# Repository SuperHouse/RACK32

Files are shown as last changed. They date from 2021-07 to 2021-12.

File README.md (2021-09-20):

Rack32 ESP32 rack-mount controller with Ethernet
================================================

Copyright 2021 SuperHouse Automation Pty Ltd  www.superhouse.tv

A general purpose control board for rack mount projects, compatible
with the [Open eXtensible Rack System](https://oxrs.io/).

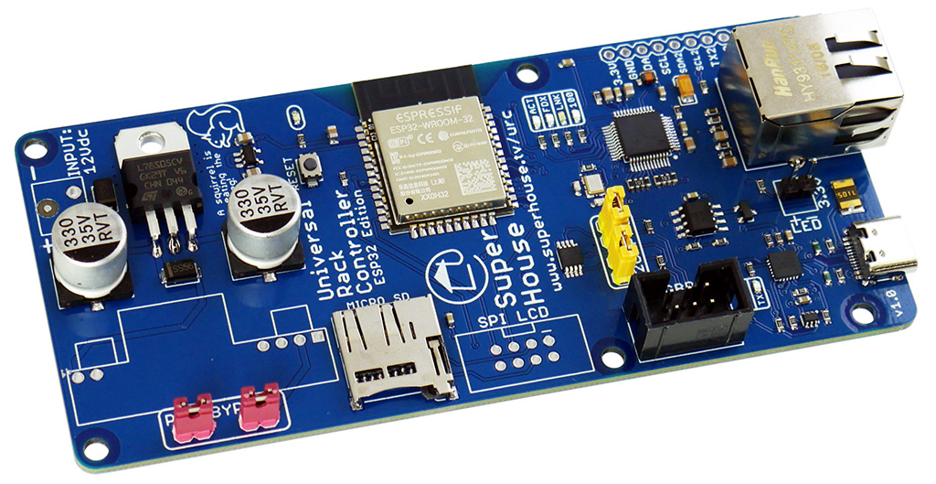
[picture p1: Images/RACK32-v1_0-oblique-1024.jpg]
Rack32 PCB


DIY rack-mount projects often require an Ethernet connection, a
status display, power regulation, and other features that are not
specific to the project.

This board fits into a rack-mount case and provides those common
features so they don't have to be recreated every time.

Features:

 * ESP32 microcontroller with WiFi.
 * 10/100Mbps Ethernet.
 * Support for both DIY (12V) PoE and 48V 802.3af PoE.
 * Pluggable terminal block for optional external DC power input.
 * Automotive-grade voltage regulator for harsh electrical environments.
 * 6-way IDC "I2C-Breakout" header for linking to other boards.
 * 8-way IDC "SPI-LCD" header for connection to an LCD.
 * USB-C connector for loading firmware.
 * Auto power source selection between USB-C, PoE, and external DC.
 * I/O header with power, 2 x I2C ports, and second hardware serial port.
 * Micro SD card slot for config files, logs, and media storage.
 * Onboard temperature sensor.
 * Header for front-panel power LED.
 * Can be built with onboard PCB antenna or external WiFi antenna.

More information:

  [www.superhouse.tv/rack32](http://www.superhouse.tv/rack32)

INSTALLATION
------------
The design is saved as an EAGLE project. EAGLE PCB design software is
available from www.cadsoftusa.com free for non-commercial use. To use
this project download it and place the directory containing these files
into the "eagle" directory on your computer. Then open EAGLE and
navigate to the project.

CREDITS
-------
Designed by Jonathan Oxer jon@oxer.com.au

DISTRIBUTION
------------
The specific terms of distribution of this project are governed by the
license referenced below.

LICENSE
-------
Licensed under the TAPR Open Hardware License (www.tapr.org/OHL).
The "license" folder within this repository also contains a copy of
this license in plain text format.

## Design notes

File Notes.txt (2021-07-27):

TFT control with CS tied to GND:

https://github.com/Bodmer/TFT_eSPI/issues/163

https://www.instructables.com/Adding-CS-Pin-to-13-LCD/

These Adafruit modules solve the CS pin problem and have an onboard micro SD
card slot, but they're very expensive. We could make different carrier
boards for this or the dodgy AliExpress ones that don't have CS. Maybe a
tri-state buffer on the carrier board to avoid having to rework the cheap
displays?

https://learn.adafruit.com/adafruit-1-3-and-1-54-240-x-240-wide-angle-tft-lcd-displays?view=all

Pins required:
Pin  ESP32          LCD
1    GND            GND
2    3.3V           VCC (should be compatible with either 3.3V or 5V)
3    IO18_SCLK      TFT_SCLK
4    IO23_COPI      TFT_COPI
5    IO4_TFT_RST    TFT_RST
6    IO2_TFT_DC     TFT_DC
7    IO ?           TFT_BLK (backlight control)
8    IO ?           TFT_CS (doesn't exist on cheap module: control buffer?)

  IO22   TFT_CIPO (not used on cheap module: required for Adafruit with micro SD card)

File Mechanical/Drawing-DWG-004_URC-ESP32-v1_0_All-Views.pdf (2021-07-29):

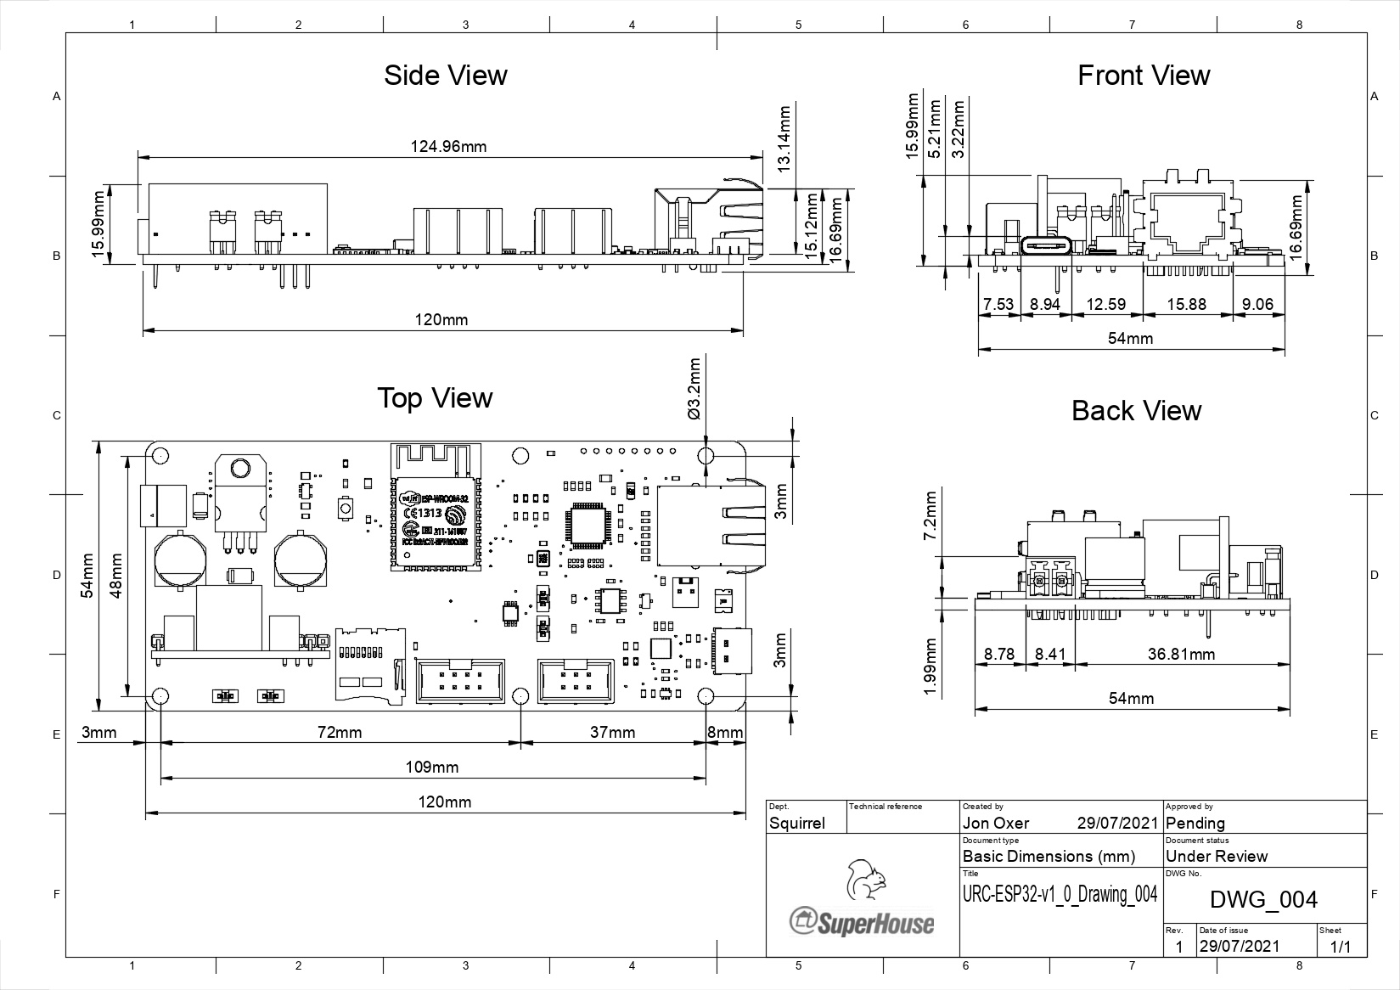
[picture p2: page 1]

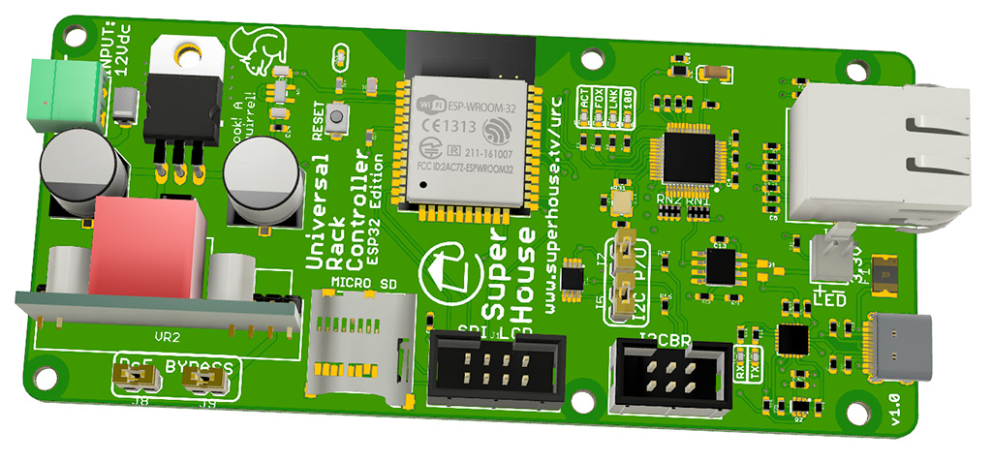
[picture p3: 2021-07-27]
Images/URC-ESP32-v1_0-render.jpg

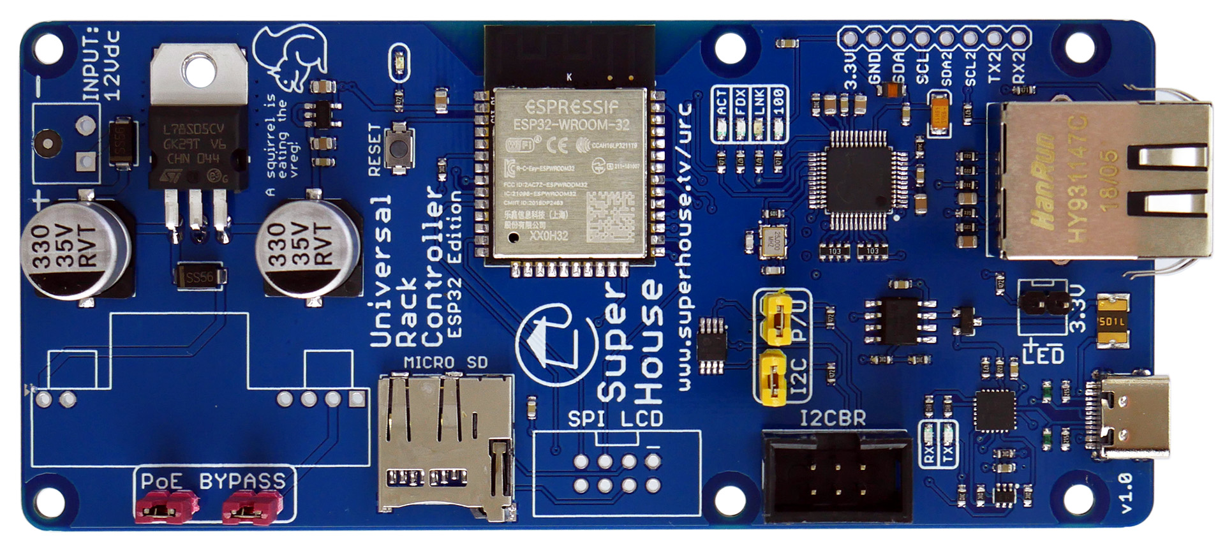
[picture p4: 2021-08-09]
Images/RACK32-v1_0-top.jpg

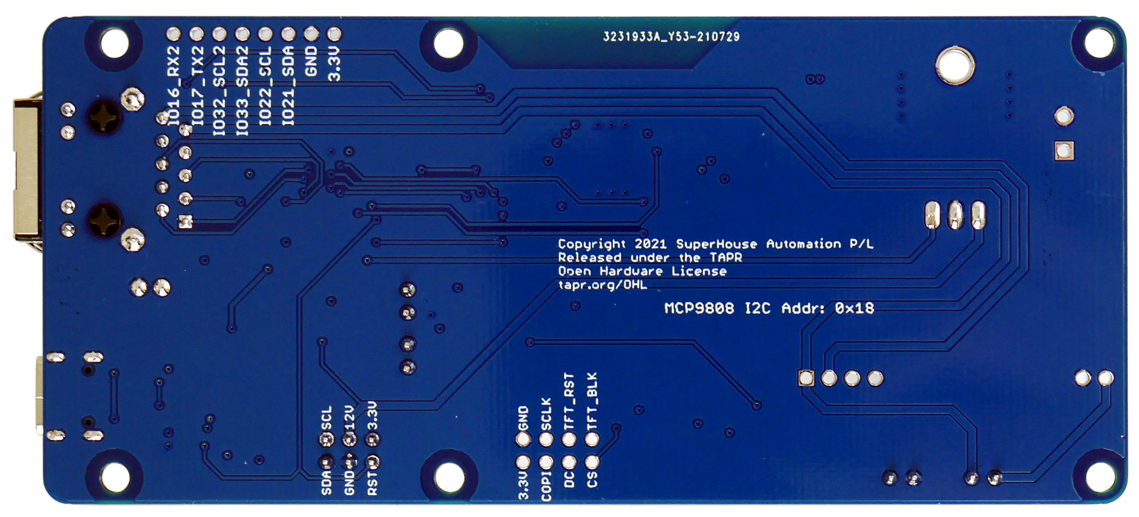
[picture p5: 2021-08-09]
Images/RACK32-v1_0-bottom.jpg

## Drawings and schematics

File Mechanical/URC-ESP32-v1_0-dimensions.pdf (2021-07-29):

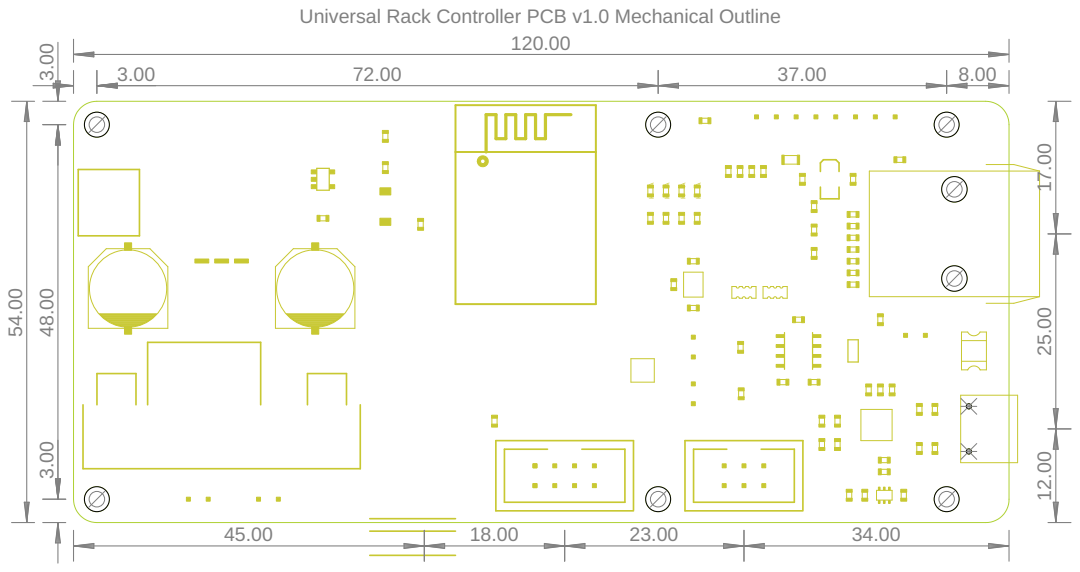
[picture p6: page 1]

Universal Rack Controller PCB v1.0 Mechanical Outline

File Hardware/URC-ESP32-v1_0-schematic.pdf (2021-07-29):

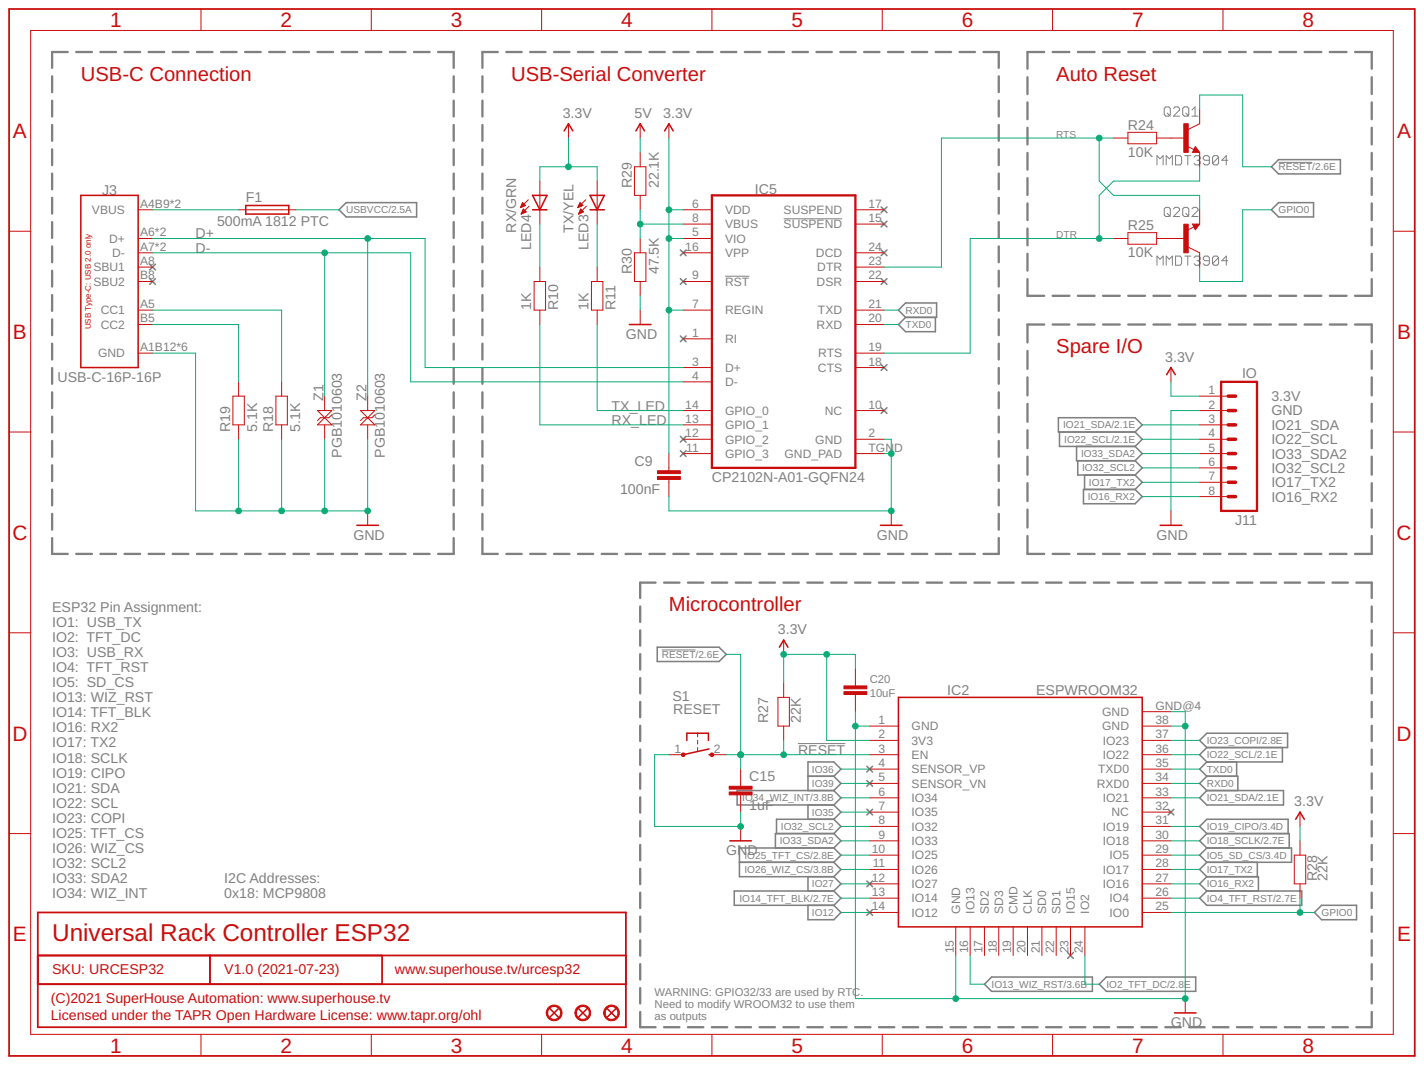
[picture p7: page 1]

8 | | 15 SUSPEND
5 | | 24

USB Type-C: USB 2.0 only

TX_LED | 14

2 | 37 GND
3 | 36

SKU: URCESP32
(C)2021 SuperHouse Automation: www.superhouse.tv Licensed under the TAPR Open Hardware License: www.tapr.org/ohl

WARNING: GPIO32/33 are used by RTC. Need to modify WROOM32 to use them
as outputs

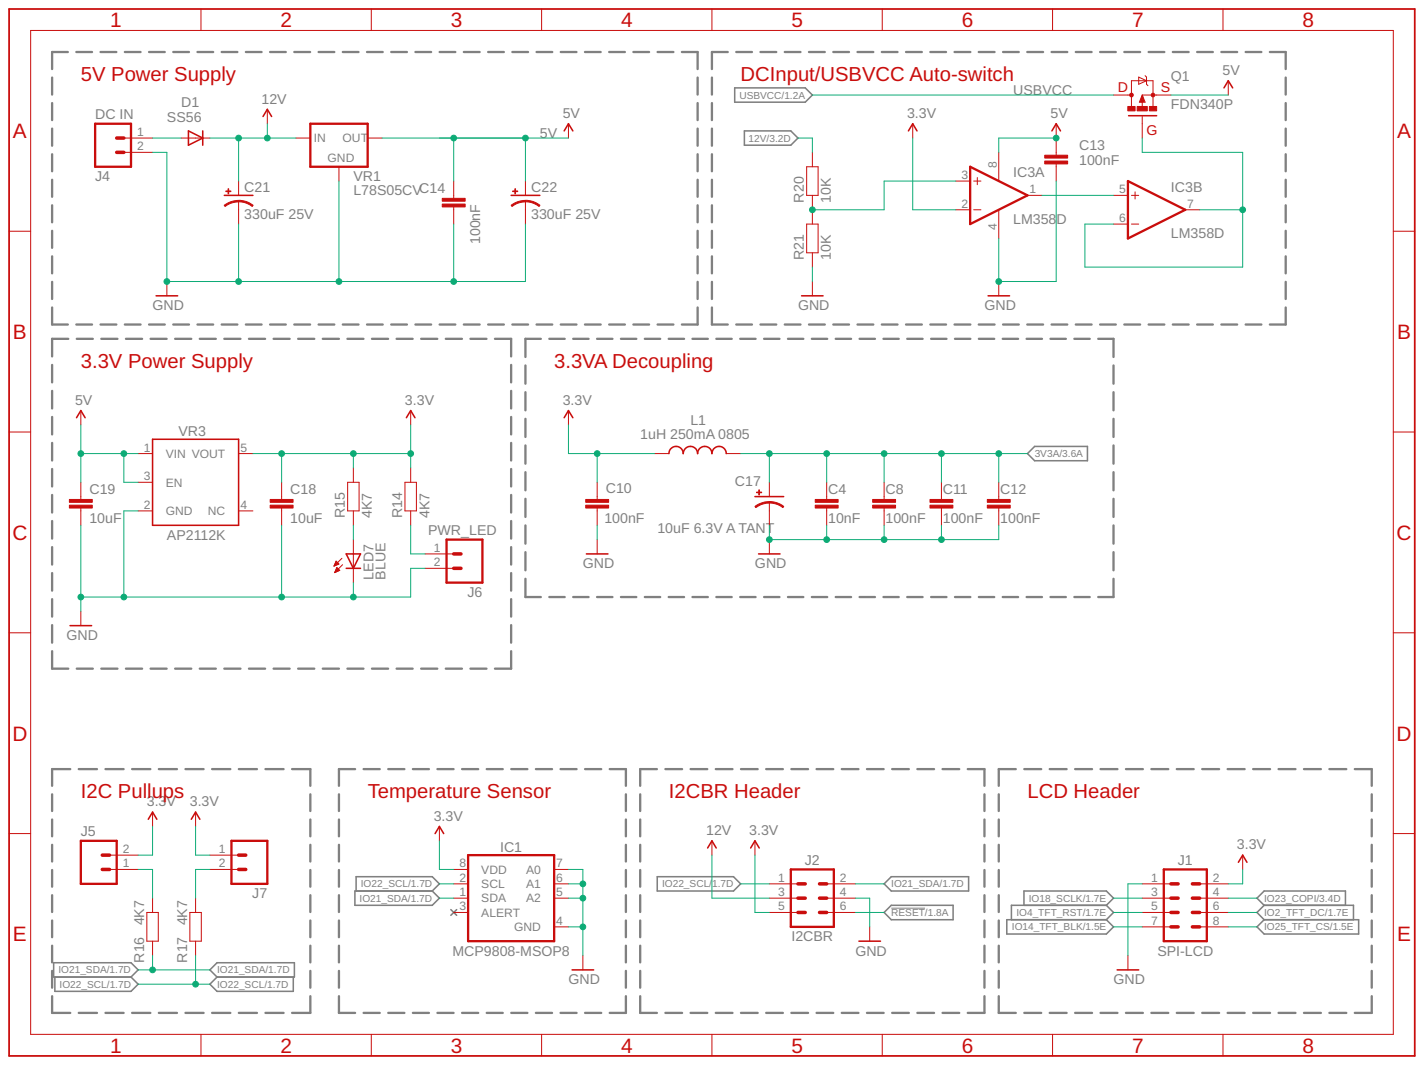
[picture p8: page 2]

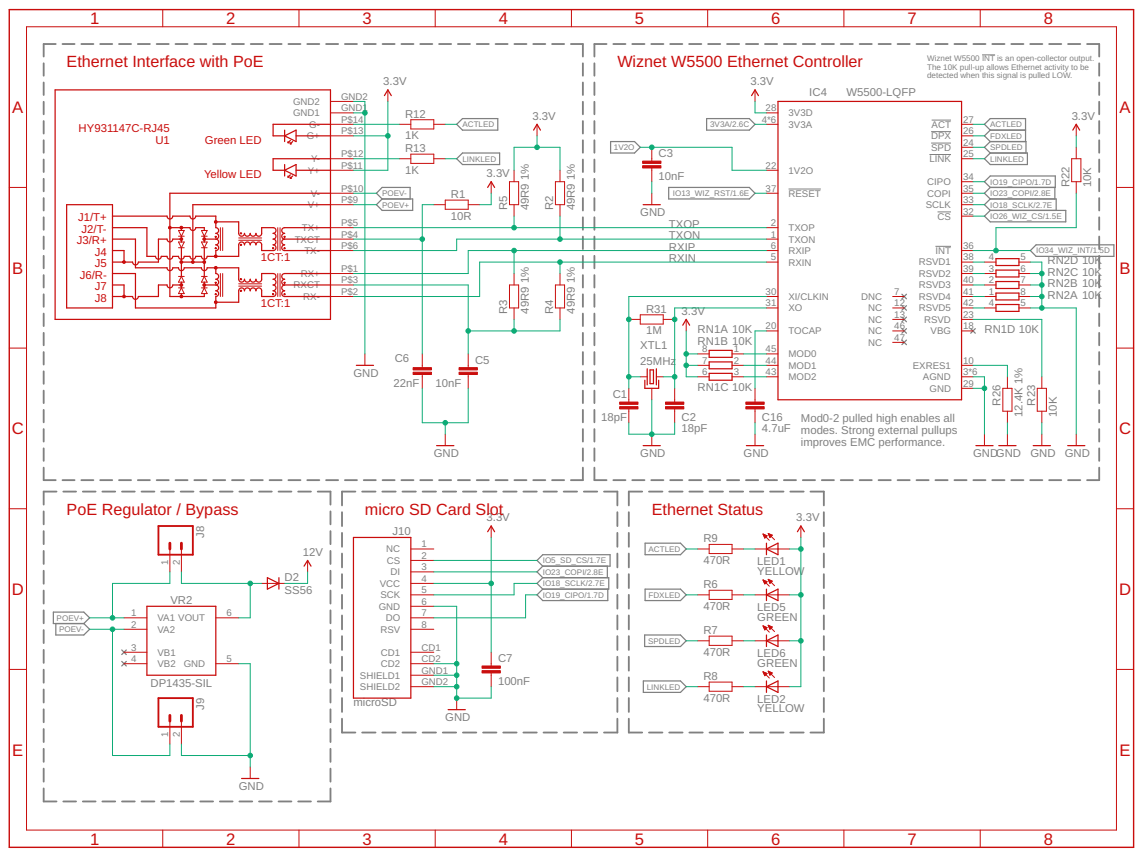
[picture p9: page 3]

Wiznet W5500 INT is an open-collector output. The 10K pull-up allows Ethernet activity to be

detected when this signal is pulled LOW.

7 2
6 3 | 3*6

Mod0-2 pulled high enables all modes. Strong external pullups

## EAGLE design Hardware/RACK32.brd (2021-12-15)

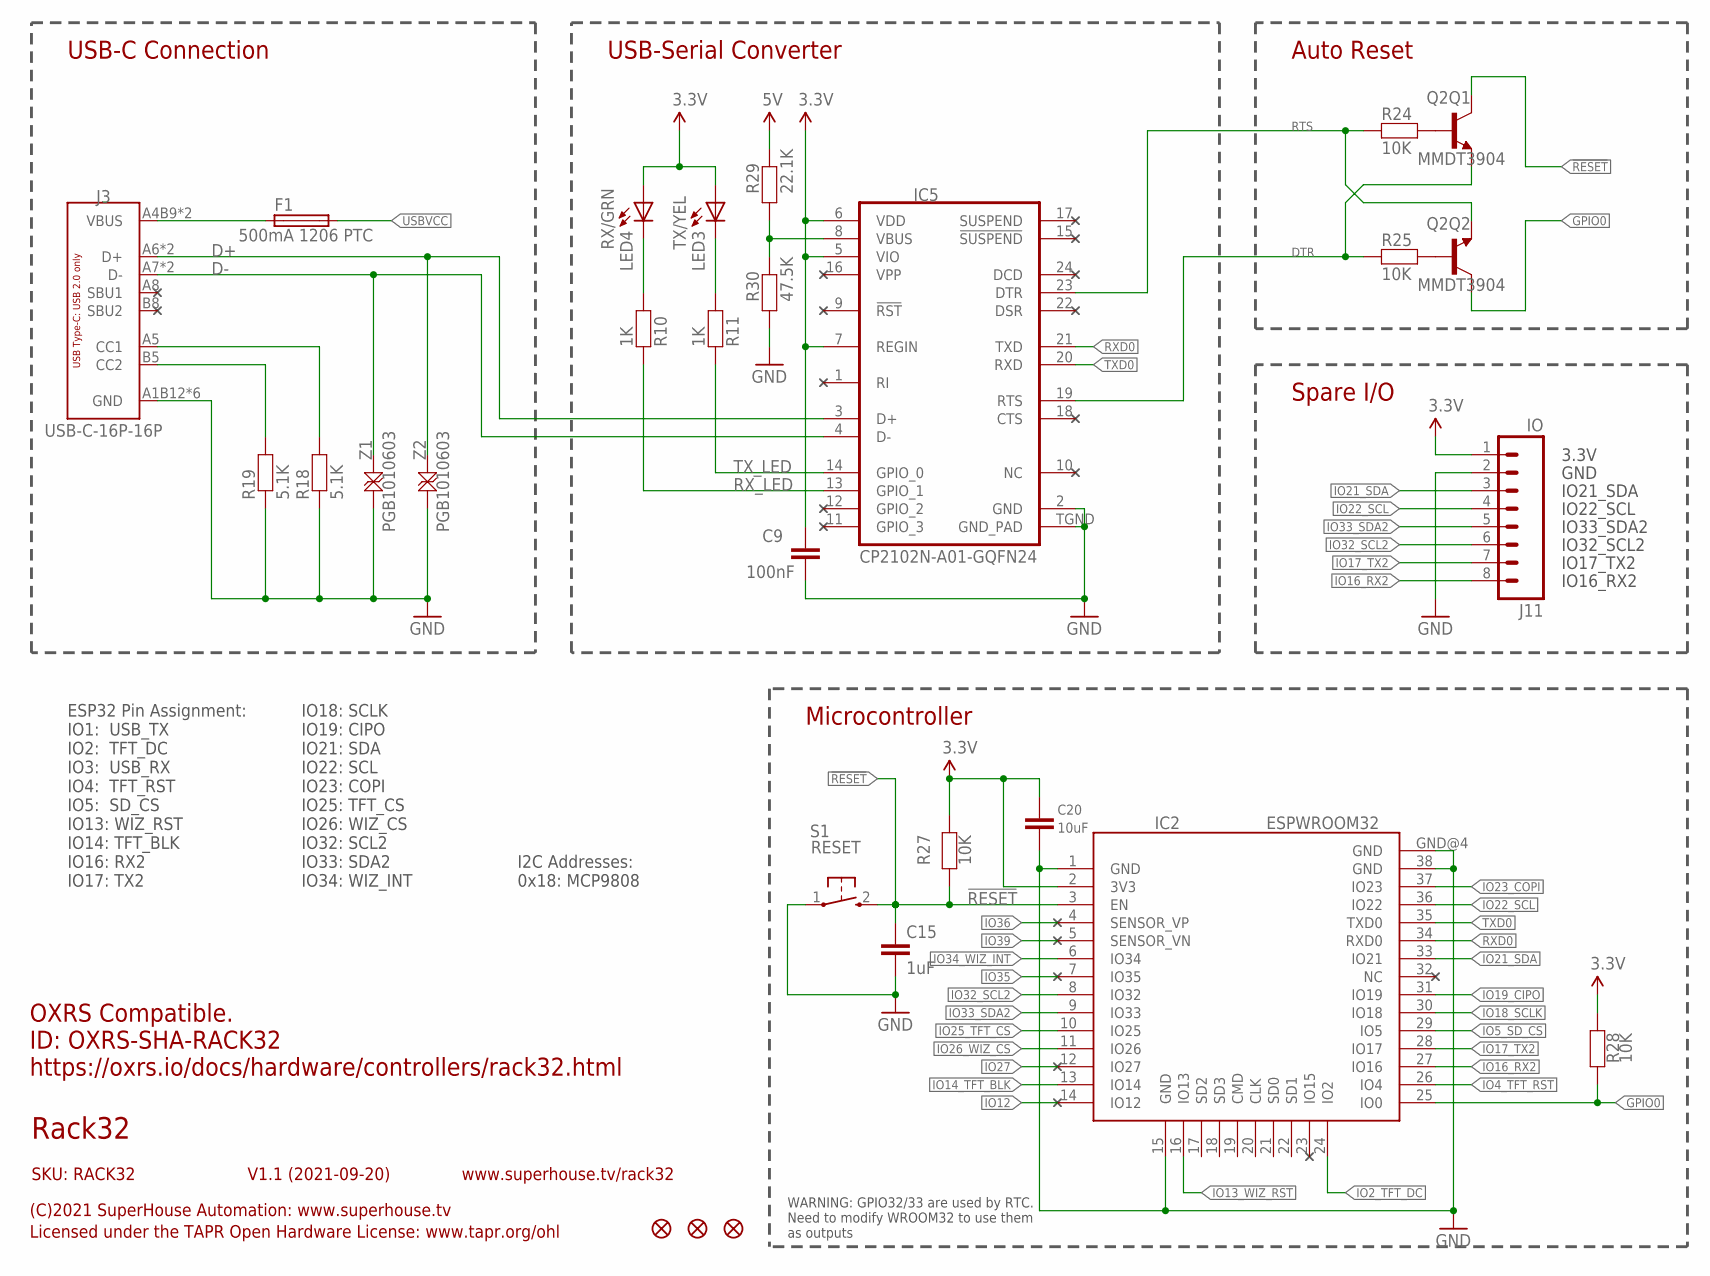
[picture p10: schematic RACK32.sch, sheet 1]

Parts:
C9: 100nF; C0603
C15: 1uF; C0603
C20: 10uF; C0805
F1: 500mA 1206 PTC; 1206
FID1, FID2, FID3: FIDUCIAL1X2.5; FIDUCIAL-1X2.5
IC2: ESPWROOM32
IC5: CP2102N-A01-GQFN24; QFN-24
J3: USB-C-16P-16P; USB-C-16P
J11: IO; 1X08
LED3: TX/YEL; LED-0603
LED4: RX/GRN; LED-0603
Q2: MMDT3904; SOT-363
R10, R11: 1K; R0603
R18, R19: 5.1K; R0603
R24, R25, R27, R28: 10K; R0603
R29: 22.1K; R0603
R30: 47.5K; R0603
S1: RESET; TACTILE_SMT_3X4X2
Z1, Z2: PGB1010603; TVS0603

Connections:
3.3V: C9.1, C20.1, IC2.2 (3V3), IC5.5 (VIO), IC5.6 (VDD), IC5.7 (REGIN), J11.1, LED3.A, LED4.A, R27.1, R28.1; also elsewhere on the board
5V: R29.2; also elsewhere on the board
!RESET: C15.1, IC2.3 (EN), Q2.3 (C), R27.2, S1.2 (S); also elsewhere on the board
D+: IC5.3 (D+), J3.A6 (D+), J3.B6 (D+), Z2.2
D-: IC5.4 (D-), J3.A7 (D-), J3.B7 (D-), Z1.2
DTR: IC5.23 (DTR), Q2.1 (E), R24.1
GND: C9.2, C15.2, C20.2, IC2.1 (GND), IC2.15 (GND), IC2.38 (GND), IC2.GND@4 (GND), IC5.2 (GND), IC5.TGND (GND_PAD), J3.A1B12 (GND), J3.A12B1 (GND), J3.FIX1 (GND), J3.FIX2 (GND), J3.FIX3 (GND), J3.FIX4 (GND), J11.2, R18.1, R19.1, R30.1, S1.1, Z1.1, Z2.1; also elsewhere on the board
GPIO0: IC2.25 (IO0), Q2.6 (C), R28.2
IO2_TFT_DC: IC2.24 (IO2); also elsewhere on the board
IO4_TFT_RST: IC2.26 (IO4); also elsewhere on the board
IO5_SD_CS: IC2.29 (IO5); also elsewhere on the board
IO12: IC2.14 (IO12)
IO13_WIZ_RST: IC2.16 (IO13); also elsewhere on the board
IO14_TFT_BLK: IC2.13 (IO14); also elsewhere on the board
IO16_RX2: IC2.27 (IO16), J11.8
IO17_TX2: IC2.28 (IO17), J11.7
IO18_SCLK: IC2.30 (IO18); also elsewhere on the board
IO19_CIPO: IC2.31 (IO19); also elsewhere on the board
IO21_SDA: IC2.33 (IO21), J11.3; also elsewhere on the board
IO22_SCL: IC2.36 (IO22), J11.4; also elsewhere on the board
IO23_COPI: IC2.37 (IO23); also elsewhere on the board
IO25_TFT_CS: IC2.10 (IO25); also elsewhere on the board
IO26_WIZ_CS: IC2.11 (IO26); also elsewhere on the board
IO27: IC2.12 (IO27)
IO32_SCL2: IC2.8 (IO32), J11.6
IO33_SDA2: IC2.9 (IO33), J11.5
IO34_WIZ_INT: IC2.6 (IO34); also elsewhere on the board
IO35: IC2.7 (IO35)
IO36: IC2.4 (SENSOR_VP)
IO39: IC2.5 (SENSOR_VN)
unnamed: Q2.2 (B), R25.2
unnamed: J3.B5 (CC2), R19.2
unnamed: J3.A5 (CC1), R18.2
unnamed: Q2.5 (B), R24.2
unnamed: LED3.C, R11.2
unnamed: LED4.C, R10.2
unnamed: IC5.8 (VBUS), R29.1, R30.2
RTS: IC5.19 (RTS), Q2.4 (E), R25.1
RXD0: IC2.34 (RXD0), IC5.21 (TXD)
RX_LED: IC5.13 (GPIO_1), R10.1
TXD0: IC2.35 (TXD0), IC5.20 (RXD)
TX_LED: IC5.14 (GPIO_0), R11.1
USBVCC: F1.2; also elsewhere on the board
USBVIN: F1.1, J3.A4B9 (VBUS), J3.A9B4 (VBUS)

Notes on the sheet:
USB-C Connection
USB-Serial Converter
Auto Reset
Microcontroller
WARNING: GPIO32/33 are used by RTC. Need to modify WROOM32 to use them as outputs
I2C Addresses: 0x18: MCP9808
ESP32 Pin Assignment: IO1: USB_TX IO2: TFT_DC IO3: USB_RX IO4: TFT_RST IO5: SD_CS IO13: WIZ_RST IO14: TFT_BLK IO16: RX2 IO17: TX2
Rack32
SKU: RACK32
(C)2021 SuperHouse Automation: www.superhouse.tv
Licensed under the TAPR Open Hardware License: www.tapr.org/ohl
www.superhouse.tv/rack32
V1.1 (2021-09-20)
Spare I/O
3.3V
GND
IO21_SDA
IO22_SCL
IO33_SDA2
IO32_SCL2
IO17_TX2
IO16_RX2
OXRS Compatible. ID: OXRS-SHA-RACK32 https://oxrs.io/docs/hardware/controllers/rack32.html
IO18: SCLK IO19: CIPO IO21: SDA IO22: SCL IO23: COPI IO25: TFT_CS IO26: WIZ_CS IO32: SCL2 IO33: SDA2 IO34: WIZ_INT

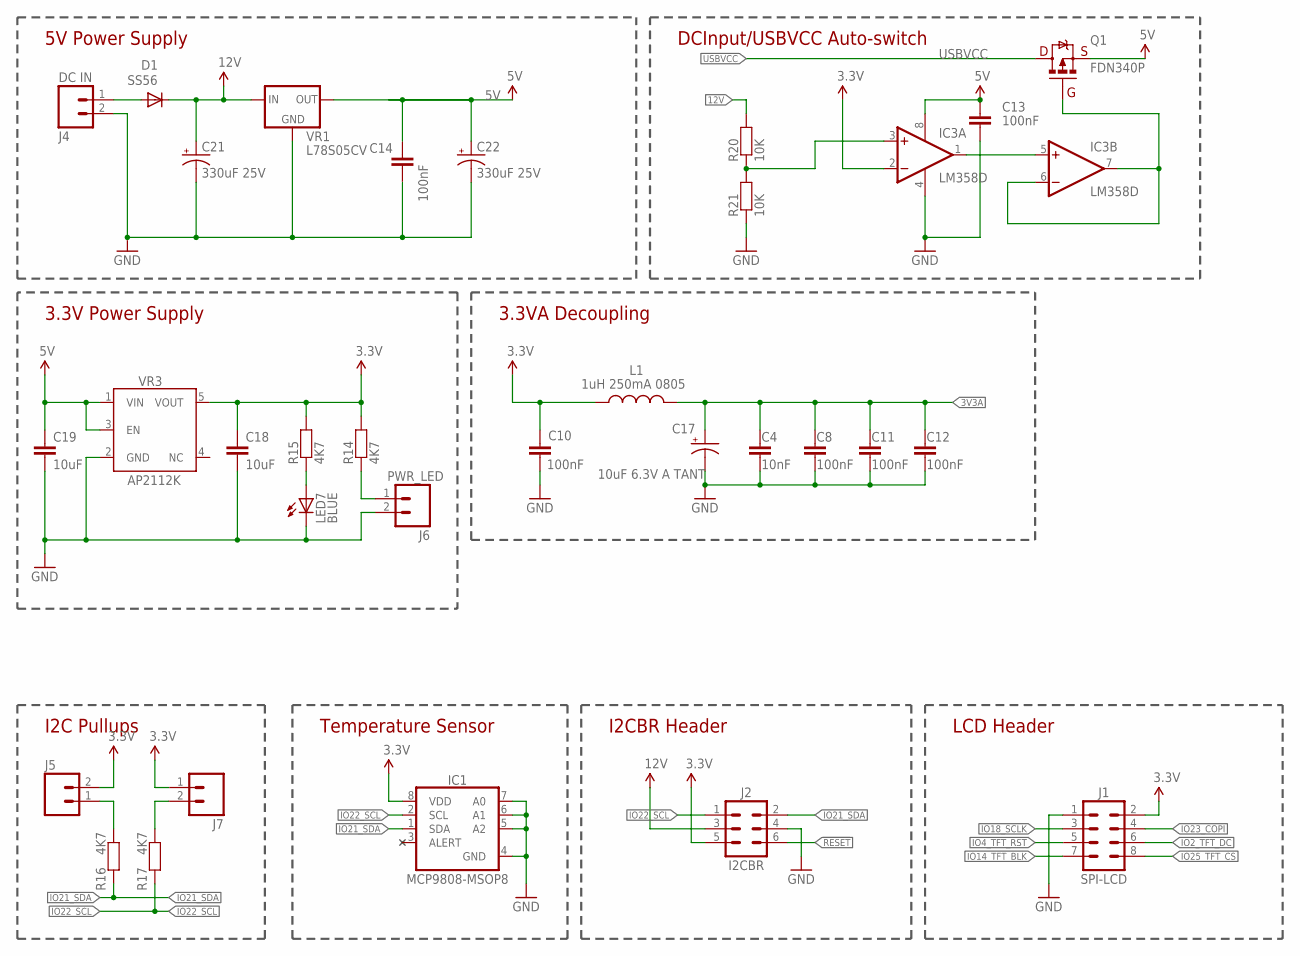
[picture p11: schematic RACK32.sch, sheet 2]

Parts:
C4: 10nF; C0603
C8, C10, C11, C12, C13, C14: 100nF; C0603
C17: 10uF 6.3V A TANT; EIA3216
C18, C19: 10uF; C0805
C21, C22: 330uF 25V; PANASONIC_G
D1: SS56; SMA-DIODE
IC1: MCP9808-MSOP8; MSOP-8
IC3: LM358D; SO08
J1: SPI-LCD; 2X04-2.54-SHROUDED
J2: I2CBR; 2X3-2.54-SHROUDED
J4: DC IN; SCREWTERMINAL-3.81MM-HOR-2
J5, J7: M02-PIN-JUMP-Y; 1X02-P-JUMP-Y
J6: PWR_LED; 1X02-P
L1: 1uH 250mA 0805; L2012C
LED7: BLUE; LED-0603
Q1: FDN340P; SOT23-3
R14, R15, R16, R17: 4K7; R0603
R20, R21: 10K; R0603
VR1: L78S05CV; TO220
VR3: AP2112KSOT25; SOT23-5

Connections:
3.3V: C10.1, C18.1, IC1.8 (VDD), IC3.2 (-IN), J1.2, J2.5, J5.2, J7.1, L1.1, R14.2, R15.2, VR3.5 (VOUT); also elsewhere on the board
3V3A: C4.1, C8.1, C11.1, C12.1, C17.A (+), L1.2; also elsewhere on the board
5V: C13.1, C14.1, C19.1, C22.+, IC3.8 (V+), Q1.2 (S), VR1.3 (OUT), VR3.1 (VIN), VR3.3 (EN); also elsewhere on the board
12V: C21.+, D1.C, J2.3, R20.2, VR1.1 (IN); also elsewhere on the board
!RESET: J2.6; also elsewhere on the board
GND: C4.2, C8.2, C10.2, C11.2, C12.2, C13.2, C14.2, C17.C (-), C18.2, C19.2, C21.-, C22.-, IC1.4 (GND), IC1.5 (A2), IC1.6 (A1), IC1.7 (A0), IC3.4 (V-), J1.1, J2.4, J4.2, J6.2, LED7.C, R21.1, VR1.2 (GND), VR1.HEATSINK (GND), VR1.TAB (GND), VR3.2 (GND); also elsewhere on the board
IO2_TFT_DC: J1.6; also elsewhere on the board
IO4_TFT_RST: J1.5; also elsewhere on the board
IO14_TFT_BLK: J1.7; also elsewhere on the board
IO18_SCLK: J1.3; also elsewhere on the board
IO21_SDA: IC1.1 (SDA), J2.2, R16.2; also elsewhere on the board
IO22_SCL: IC1.2 (SCL), J2.1, R17.2; also elsewhere on the board
IO23_COPI: J1.4; also elsewhere on the board
IO25_TFT_CS: J1.8; also elsewhere on the board
unnamed: LED7.A, R15.1
unnamed: J6.1, R14.1
unnamed: J5.1, R16.1
unnamed: J7.2, R17.1
unnamed: IC3.3 (+IN), R20.1, R21.2
unnamed: IC3.6 (-IN), IC3.7 (OUT), Q1.1 (G)
unnamed: IC3.1 (OUT), IC3.5 (+IN)
unnamed: D1.A, J4.1
USBVCC: Q1.3 (D); also elsewhere on the board

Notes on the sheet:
5V Power Supply
DCInput/USBVCC Auto-switch
3.3VA Decoupling
3.3V Power Supply
LCD Header
I2CBR Header
Temperature Sensor
I2C Pullups

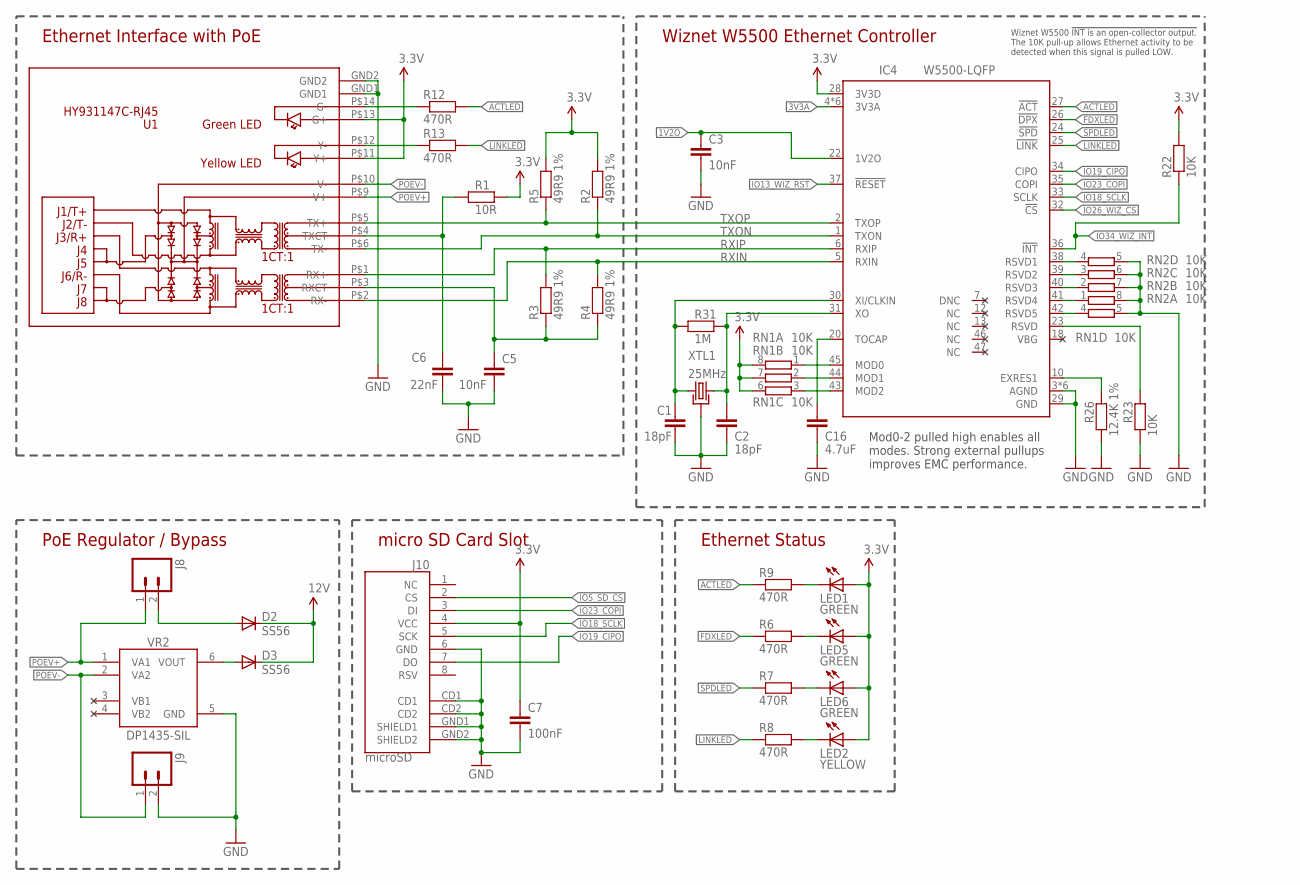
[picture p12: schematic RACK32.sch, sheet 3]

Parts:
C1, C2: 18pF; C0603
C3, C5: 10nF; C0603
C6: 22nF; C0603
C7: 100nF; C0603
C16: 4.7uF; C0603
D2, D3: SS56; SMA-DIODE
IC4: W5500-LQFP; LQFP48
J8, J9: M02-PIN-JUMP-Y; 1X02-P-JUMP-Y
J10: microSD; MICRO-SD-SOCKET-PP
LED1, LED5, LED6: GREEN; LED-0603
LED2: YELLOW; LED-0603
R1: 10R; R0603
R2, R3, R4, R5: 49R9 1%; R0603
R6, R7, R8, R9, R12, R13: 470R; R0603
R22, R23: 10K; R0603
R26: 12.4K 1%; R0603
R31: 1M; R0603
RN1, RN2: 10K; CAY16
U1: HY931147C-RJ45; HY931147C
VR2: DP1435-SIL; DP1435
XTL1: 25MHz; CRYSTAL-SMD-3X2

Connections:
1V2O: C3.1, IC4.22 (1V2O)
3.3V: C7.1, IC4.28 (3V3D), J10.4 (VCC), LED1.A, LED2.A, LED5.A, LED6.A, R1.1, R2.2, R5.2, R22.2, RN1.6 (2), RN1.7 (2), RN1.8 (2), U1.P$11 (Y+), U1.P$13 (G+); also elsewhere on the board
3V3A: IC4.4 (3V3A), IC4.8 (3V3A), IC4.11 (3V3A), IC4.15 (3V3A), IC4.17 (3V3A), IC4.21 (3V3A); also elsewhere on the board
12V: D2.C, D3.C; also elsewhere on the board
ACTLED: IC4.27 (!ACT), R9.1, R12.2
FDXLED: IC4.26 (!DPX), R6.1
GND: C1.2, C2.2, C3.2, C5.2, C6.2, C7.2, C16.2, IC4.3 (AGND), IC4.9 (AGND), IC4.14 (AGND), IC4.16 (AGND), IC4.19 (AGND), IC4.29 (GND), IC4.48 (AGND), J9.2, J10.6 (GND), J10.CD1, J10.CD2, J10.GND1 (SHIELD1), J10.GND2 (SHIELD2), R23.2, R26.2, RN1.5 (2), RN2.5 (2), RN2.6 (2), RN2.7 (2), RN2.8 (2), U1.GND1, U1.GND2, VR2.5 (GND), XTL1.2 (GND), XTL1.4 (GND); also elsewhere on the board
IO5_SD_CS: J10.2 (CS); also elsewhere on the board
IO13_WIZ_RST: IC4.37 (!RESET); also elsewhere on the board
IO18_SCLK: IC4.33 (SCLK), J10.5 (SCK); also elsewhere on the board
IO19_CIPO: IC4.34 (CIPO), J10.7 (DO); also elsewhere on the board
IO23_COPI: IC4.35 (COPI), J10.3 (DI); also elsewhere on the board
IO26_WIZ_CS: IC4.32 (!CS); also elsewhere on the board
IO34_WIZ_INT: IC4.36 (!INT), R22.1; also elsewhere on the board
LINKLED: IC4.25 (!LINK), R8.1, R13.2
unnamed: C5.1, R3.1, R4.1, U1.P$3 (RXCT)
unnamed: D2.A, J8.2
unnamed: C2.1, IC4.31 (XO), R31.1, XTL1.3 (2)
unnamed: D3.A, VR2.6 (VOUT)
unnamed: LED6.C, R7.2
unnamed: C1.1, IC4.30 (XI/CLKIN), R31.2, XTL1.1
unnamed: LED2.C, R8.2
unnamed: C16.1, IC4.20 (TOCAP)
unnamed: C6.1, R1.2, U1.P$4 (TXCT)
unnamed: IC4.10 (EXRES1), R26.1
unnamed: IC4.23 (RSVD), R23.1
unnamed: IC4.45 (MOD0), RN1.1
unnamed: IC4.44 (MOD1), RN1.2 (1)
unnamed: IC4.43 (MOD2), RN1.3 (1)
unnamed: IC4.42 (RSVD5), RN1.4 (1)
unnamed: IC4.41 (RSVD4), RN2.1
unnamed: IC4.40 (RSVD3), RN2.2 (1)
unnamed: IC4.39 (RSVD2), RN2.3 (1)
unnamed: IC4.38 (RSVD1), RN2.4 (1)
unnamed: R12.1, U1.P$14 (G-)
unnamed: LED5.C, R6.2
unnamed: LED1.C, R9.2
unnamed: R13.1, U1.P$12 (Y-)
POEV+: J8.1, U1.P$9 (V+), VR2.1 (VA1)
POEV-: J9.1, U1.P$10 (V-), VR2.2 (VA2)
RXIN: IC4.5 (RXIN), R4.2, U1.P$2 (RX-)
RXIP: IC4.6 (RXIP), R3.2, U1.P$1 (RX+)
SPDLED: IC4.24 (!SPD), R7.1
TXON: IC4.1 (TXON), R2.1, U1.P$6 (TX-)
TXOP: IC4.2 (TXOP), R5.1, U1.P$5 (TX+)
VB1: VR2.3 (VB1)
VB2: VR2.4 (VB2)

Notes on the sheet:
micro SD Card Slot
Ethernet Status
Ethernet Interface with PoE
Wiznet W5500 Ethernet Controller
Mod0-2 pulled high enables all modes. Strong external pullups improves EMC performance.
Wiznet W5500 !INT is an open-collector output. The 10K pull-up allows Ethernet activity to be detected when this signal is pulled LOW.
PoE Regulator / Bypass

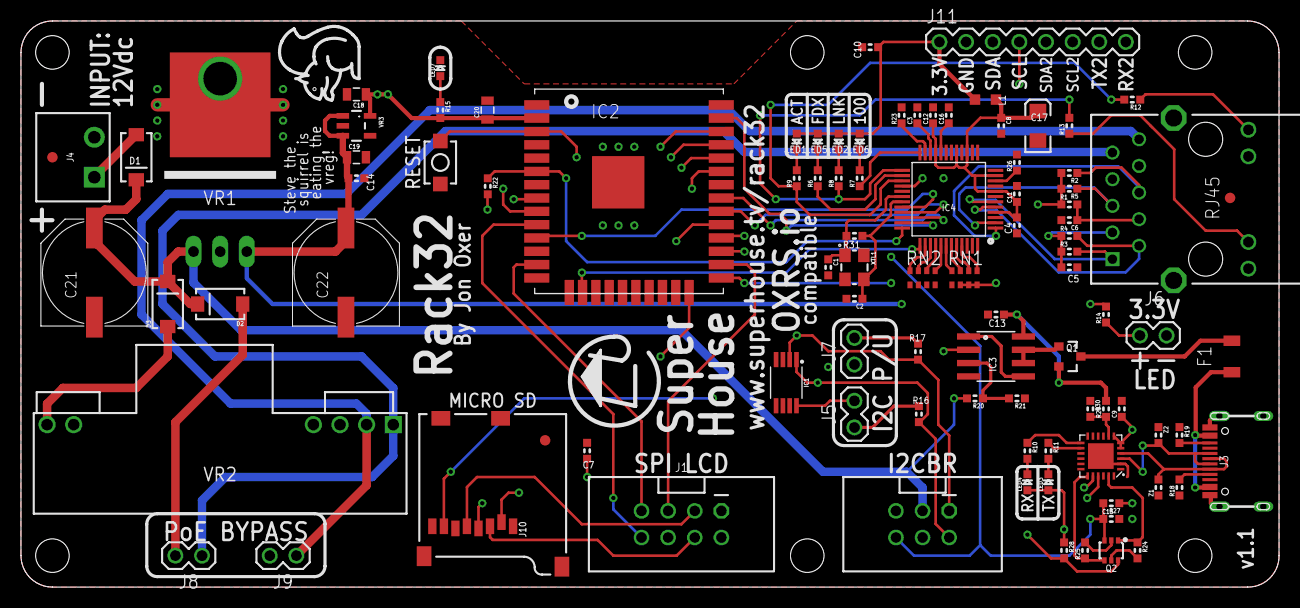
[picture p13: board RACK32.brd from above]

Board: 4 copper layers, 120.0 x 54.0 mm, 96 parts (0 on the bottom side), 83 nets.

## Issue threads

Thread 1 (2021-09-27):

mcp9808 temp sensor

austinscreations, 2021-09-27:
from a users testing and setting up the temp sensor to output to the oxrs system (mqtt) we noticed higher temp readouts. upon looking at the design my conclusion was that the temp sensor might be picking up  the heat from the esp32.

may want to consider adding a milled cut out to limit this interference in a revision.

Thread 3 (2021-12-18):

Can't log in to html

Russellthemuscle1, 2021-12-18:
I have a rack32 controller which is version 1.0.0 and can not get on to its web page.
I have tried uploading the new version from the arduino ide but I can not find the board "Rack32".

austinscreations, 2022-02-17:
early versions of rack32 weren't shipped with any preloaded firmware hence not being able to connect to any HTML page.

to load firmware via arduino IDE select in boards manager - ESP32 arduino - ESP32 Wrover Module

new rack32 boards have started to ship with pre-loaded firmware, but even these no longer have embedded HTML but instead use an extra downloadable HTML website that you can run locally

for more information look at [https://oxrs.io/](https://oxrs.io/) or join the discord group.

Russellthemuscle1, 2022-02-20:
Thank you Austin for the reply it makes sense.

Just saw the updated documentation on https://oxrs.io/docs it helps alot and looks great.

Thanks

Russell Vickery

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

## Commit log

2021-06-20 Initial import of project files.
    [URC.brd, URC.sch]
2021-07-27 Created ESP32 version of URC controller. v1.0 release
    [URC-ESP32.brd, URC-ESP32.sch]
2021-07-27 Rough start of passthrough version of URC controller.
    [URC-PASSTHROUGH.brd, URC-PASSTHROUGH.sch]
2021-07-27 Deleted obsolete files.
    [URC.brd, URC.sch]
2021-07-27 Added render of ESP32 version.
2021-07-27 Schematic progress for passthrough edition.
    [URC-PASSTHROUGH.brd, URC-PASSTHROUGH.sch]
2021-07-27 Created LCD breakout. ERC and DRC for v1.0 release.
    [URC-LCD.brd, URC-LCD.sch]
2021-07-28 Major mechanical shrinkage for revised v1.0 release.
    [URC-LCD.brd, URC-LCD.sch]
2021-07-28 Tie unused inputs to GND.
    [URC-LCD.brd, URC-LCD.sch]
2021-07-28 Renamed LCD board files because they're not specific to the URC.
    [TFTBR.brd, TFTBR.sch]
2021-07-28 Added I/O header with spare pins for I2C port 2 and serial port 2.
    [URC-ESP32.brd, URC-ESP32.sch]
2021-07-29 Added dimensions and generated PDF of measurements.
    [URC-ESP32.brd]
2021-07-29 Fixed pin allocation notes and labels in schematic. Renamed mechanical PDF to clarify its purpose. Generated schematic PDF.
    [URC-ESP32.brd, URC-ESP32.sch]
2021-07-29 Added Fusion360 and STL models of the ESP32 version of the controller.
2021-07-30 Added F3D and STEP files. Removed STL. Added PDF of TFTBR dimensions.
    [TFTBR-v1_0.f3d]
2021-08-09 Added miscellaneous images of case concepts and boards.
2021-08-09 Added usb v2 version of passthrough board.
    [URC-PASSTHROUGH-USB2.brd, URC-PASSTHROUGH-USB2.sch]
2021-08-09 Minor updates to boards.
    [TFTBR.brd, TFTBR.sch, URC-ESP32.brd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]
2021-08-09 Deleted files that are also in the URC repo.
    [TFTBR-v1_0.f3d, TFTBR.brd, TFTBR.sch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]
2021-08-09 Renamed board files to match new project name.
    [RACK32.brd, RACK32.sch]
2021-09-20 Changed PTC to 1206 size. Replaced power LED header.
    [RACK32.brd, RACK32.sch]
2021-09-20 Added backpower protection for PoE module.
    [RACK32.brd, RACK32.sch]
2021-09-22 Added link to OXRS.io on the silkscreen. Connected second SD card detect pad to GND for improved mechanical strength.
    [RACK32.brd, RACK32.sch]
2021-12-15 Library updates and routing improvements.
    [RACK32.brd, RACK32.sch]

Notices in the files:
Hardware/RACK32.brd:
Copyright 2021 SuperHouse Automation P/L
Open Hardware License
